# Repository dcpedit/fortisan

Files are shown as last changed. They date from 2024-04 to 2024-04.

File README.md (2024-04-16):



# Fortisan Tray

Fortisan is a 40% sized artisan tray.  The bottom row of the tray features movable holders that allow for various artisan sizes.

## Features

* 33x 1u tray spaces
* 2x 2u tray spaces
* 1x 7u tray space
* Movable holders on bottom row for various sized artisans (1u up to 7u)
* Uses silicone T-plugs to hold artisans in place and prevents shifting
* Matching lid

## Parts

| Description | Qty | Notes
| --- | --- | -----
| 3mm colored acrylic | 8 | Layers for tray (x3) + lid (x5)
| 1.5mm clear acrylic | 1 | Lid window
| M3x8mm chicago bolt | 6 | [Link](https://www.aliexpress.us/item/2251832451307213.html)
| M3x12mm chicago bolt | 6 | [Link](https://www.aliexpress.us/item/2251832451307213.html)
| M3x6mm screw | 6 | [Link](https://www.aliexpress.us/item/2255800885711092.html)
| Silicone T-plug (A 7.5mm) | 36 - 44 | [Link](https://www.aliexpress.us/item/3256805742804858.html)
| 2-sided tape or acrylic glue | 1

### Silicone T-plug specifications



### Assembly

Use the shaft portion of the M3x12 chicago bolts for the top part of the lid, and the M3x6 screws for the lid bottom.  Only layers #1 - #5 will be screwed together since layer #7 of the lid has large cutouts for the chicago bolts on the tray side.  Which means that you'll need to attach layer #7 to the bottom of the lid using double-sided tape or glue.

The tray section will only have 3 layers of acrylic which are held together by the M3x8 chicago bolts.  Again, use the shaft side of the bolt on top so that the slotted head is on the bottom.



Now push the silicone T-plugs through all the tray holes from bottom until they snap into place.




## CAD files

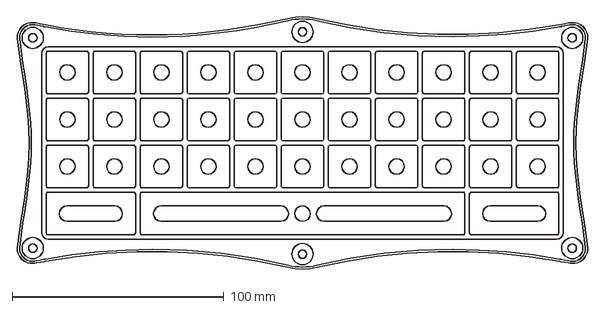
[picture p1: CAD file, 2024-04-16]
case.dxf
270.4 x 119.8 mm
